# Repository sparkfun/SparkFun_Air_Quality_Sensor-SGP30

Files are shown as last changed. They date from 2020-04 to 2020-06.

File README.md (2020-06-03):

SparkFun Air Quality Sensor - SGP30 (Qwiic)
========================================

SparkFun Air Quality Sensor - SGP30

[*SparkFun Air Quality Sensor - SGP30 (Qwiic) (SEN-16531)*](https://www.sparkfun.com/products/16531)

The SGP30 is an Indoor Air Quality Sensor that outputs TVOC (in ppb) and CO<sub>2</sub> (in ppm) values along with raw measurements of H<sub>2</sub> and Ethanol.

Repository Contents
-------------------

* **/Hardware** - Eagle design files (.brd, .sch)
* **/Production** - Production panel files (.brd)

Documentation
--------------
* **[SGP30 Arduino Library](https://github.com/sparkfun/SparkFun_SGP30_Arduino_Library)** - Arduino library for the SparkFun Air Quality Sensor - SGP30.
* **[Hookup Guide](https://learn.sparkfun.com/tutorials/sparkfun-air-quality-sensor---sgp30-qwiic-hookup-guide)** - Basic hookup guide for the SparkFun Air Quality Sensor - SGP30. 
* **[SparkFun Fritzing repo](https://github.com/sparkfun/Fritzing_Parts)** - Fritzing diagrams for SparkFun products.
* **[SparkFun 3D Model repo](https://github.com/sparkfun/3D_Models)** - 3D models of SparkFun products.

Product Versions
----------------
* [SEN-16531](https://www.sparkfun.com/products/16531) - SparkFun initial release.
* [SPX-14813](https://www.sparkfun.com/products/14813) - Original SparkX Release.

License Information
-------------------

This product is _**open source**_! 

Please review the LICENSE.md file for license information. 

If you have any questions or concerns on licensing, please contact technical support on our [SparkFun forums](https://forum.sparkfun.com/viewforum.php?f=152).

Distributed as-is; no warranty is given.

- Your friends at SparkFun.

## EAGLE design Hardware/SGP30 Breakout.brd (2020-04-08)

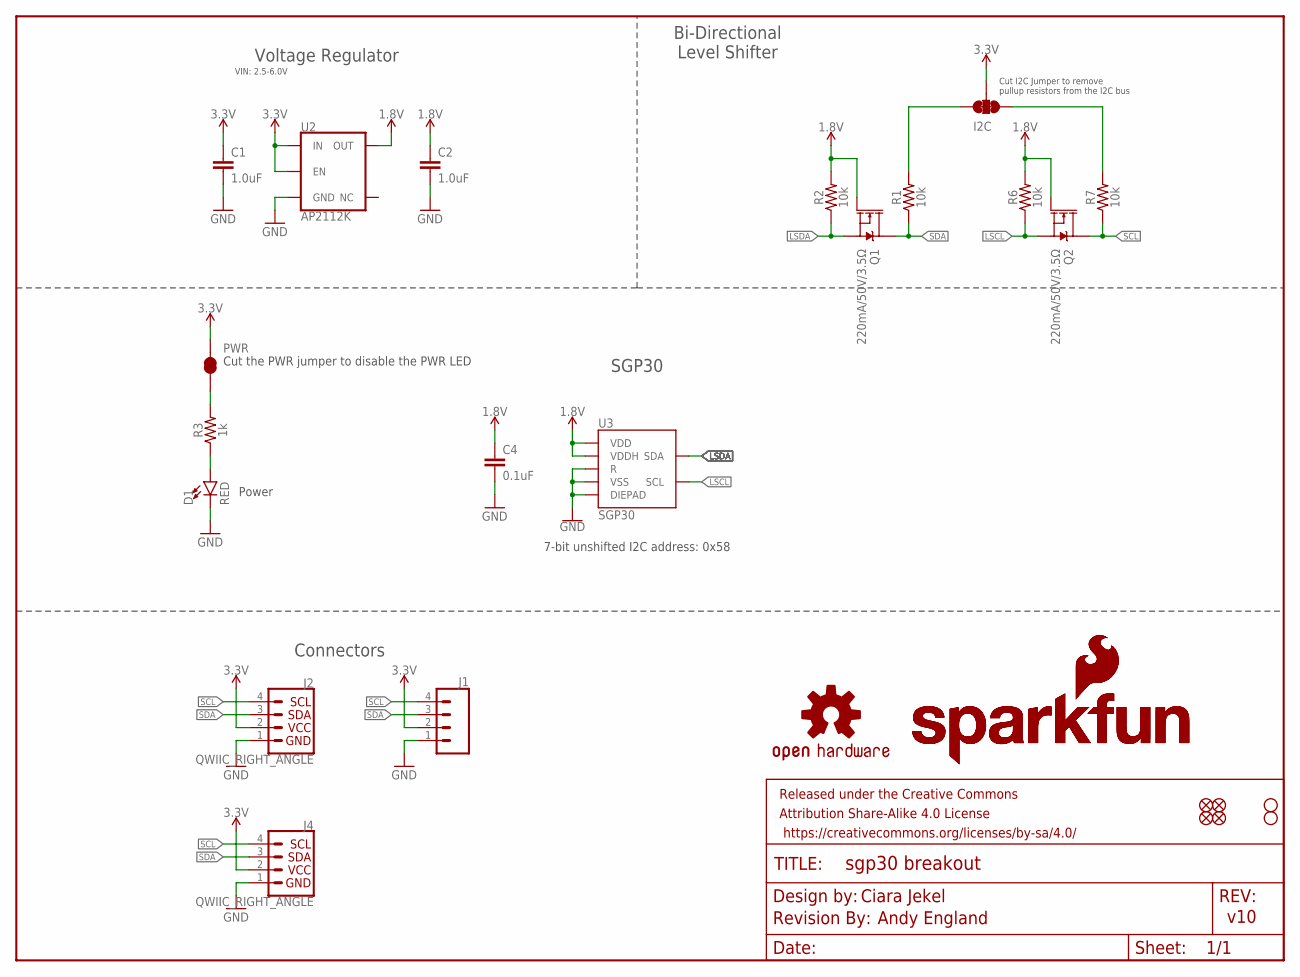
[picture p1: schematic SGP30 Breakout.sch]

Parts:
C1, C2: 1.0uF; 0603
C4: 0.1uF; 0603
D1: RED; LED-0603
FRAME1: FRAME-LETTER; CREATIVE_COMMONS
I2C: JUMPER-SMT_3_2-NC_TRACE_SILK; SMT-JUMPER_3_2-NC_TRACE_SILK
J1: CONN_041X04_NO_SILK; 1X04_NO_SILK
J2, J4: QWIIC_RIGHT_ANGLE; JST04_1MM_RA
JP1, JP2, JP5, JP6: FIDUCIALUFIDUCIAL; MICRO-FIDUCIAL
JP3, JP4: STAND-OFF
LOGO2: REVISION
LOGO3, LOGO4: SFE_LOGO_NAME_FLAME.1_INCH; SFE_LOGO_NAME_FLAME_.1
LOGO5: OSHW-LOGOS; OSHW-LOGO-S
PWR: JUMPER-SMT_2_NC_TRACE_SILK; SMT-JUMPER_2_NC_TRACE_SILK
Q1, Q2: 220mA/50V/3.5Ω; SOT23-3
R1, R2, R6, R7: 10k; 0603
R3: 1k; 0603
U2: AP2112K; SOT23-5
U3: SGP30

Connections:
1.8V: C2.1, C4.1, Q1.1 (G), Q2.1 (G), R2.2, R6.2, U2.5 (OUT), U3.1 (VDD), U3.5 (VDDH)
3.3V: C1.1, I2C.2, J1.2, J2.2, J4.2, PWR.2, U2.1 (IN), U2.3 (EN)
GND: C1.2, C2.2, C4.2, D1.C, J1.1, J2.1, J4.1, U2.2 (GND), U3.2 (VSS), U3.4 (R), U3.DIEPAD
LSCL: Q2.2 (S), R6.1, U3.6 (SCL)
LSDA: Q1.2 (S), R2.1, U3.3 (SDA)
unnamed: PWR.1, R3.2
unnamed: I2C.3, R1.2
unnamed: D1.A, R3.1
unnamed: I2C.1, R7.2
SCL: J1.4, J2.4, J4.4, Q2.3 (D), R7.1
SDA: J1.3, J2.3, J4.3, Q1.3 (D), R1.1

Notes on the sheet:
Ciara Jekel
v10
7-bit unshifted I2C address: 0x58
Power
Bi-Directional Level Shifter
Voltage Regulator
SGP30
Connectors
Cut the PWR jumper to disable the PWR LED
Andy England
VIN: 2.5-6.0V
Cut I2C Jumper to remove pullup resistors from the I2C bus

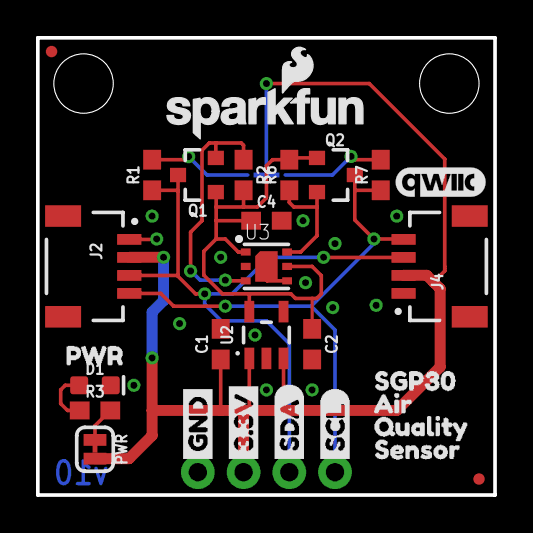
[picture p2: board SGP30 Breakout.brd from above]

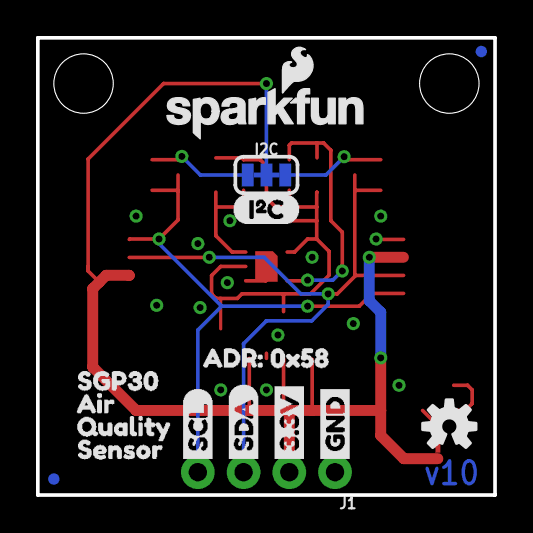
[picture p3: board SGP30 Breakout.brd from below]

Board: 2 copper layers, 25.4 x 25.4 mm, 49 parts (16 on the bottom side), 11 nets.

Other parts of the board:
U$1, U$11: _AIR1
U$2, U$12: QUALITY2
U$3, U$22: GND1
U$4, U$21: 3#3V2
U$5, U$27: SDA8
U$6, U$26: SCL9
U$7, U$13: SENSOR3
U$8, U$9: SGP300
U$14: ADR#_0X580
U$15: I2C
U$16: QWIIC_5MM
U$17: PWR_TO

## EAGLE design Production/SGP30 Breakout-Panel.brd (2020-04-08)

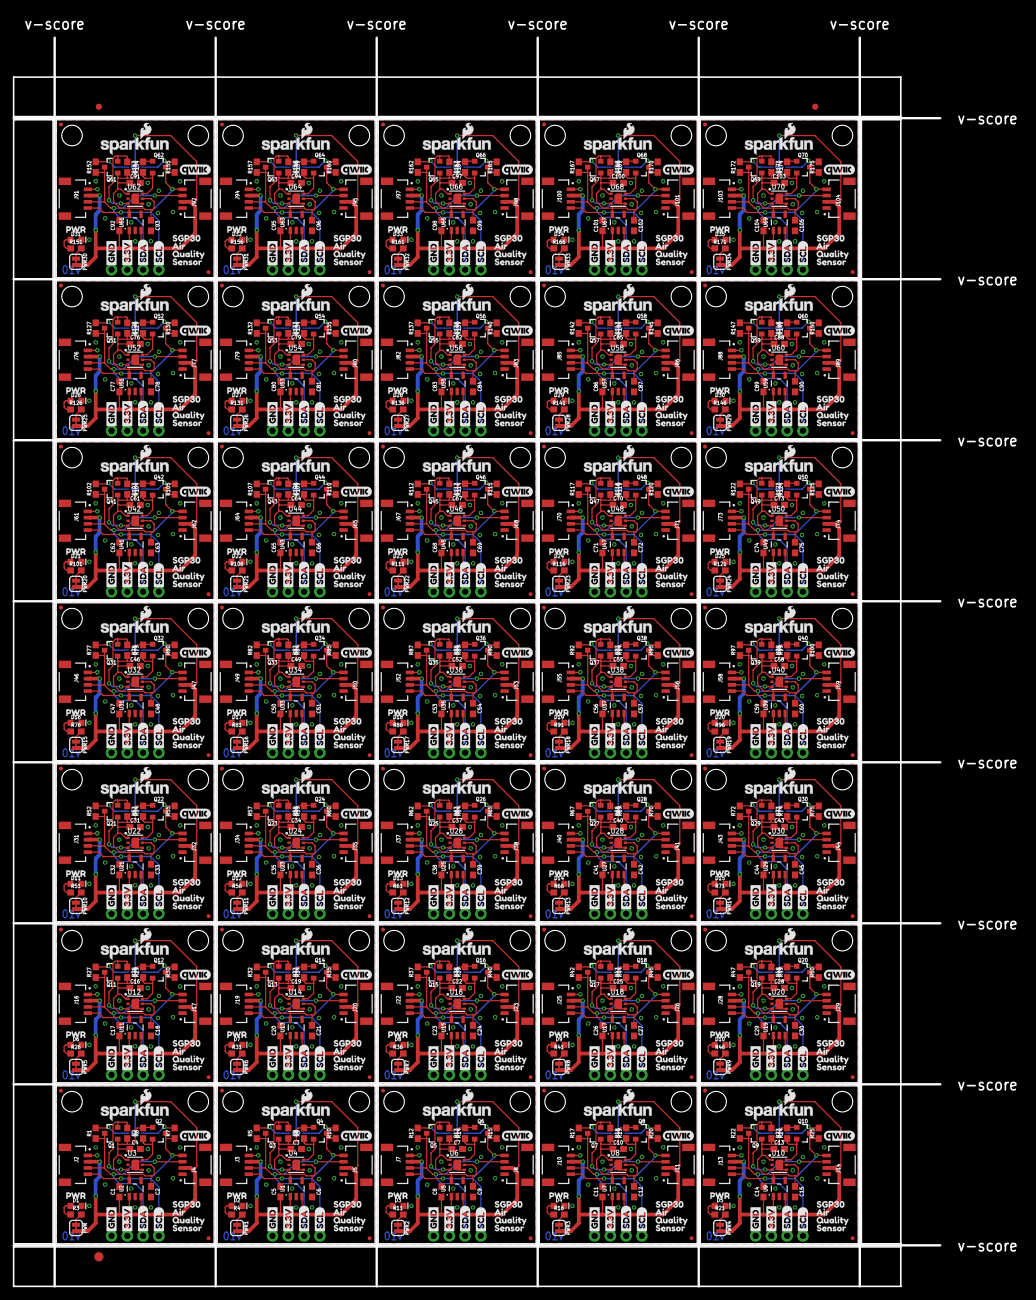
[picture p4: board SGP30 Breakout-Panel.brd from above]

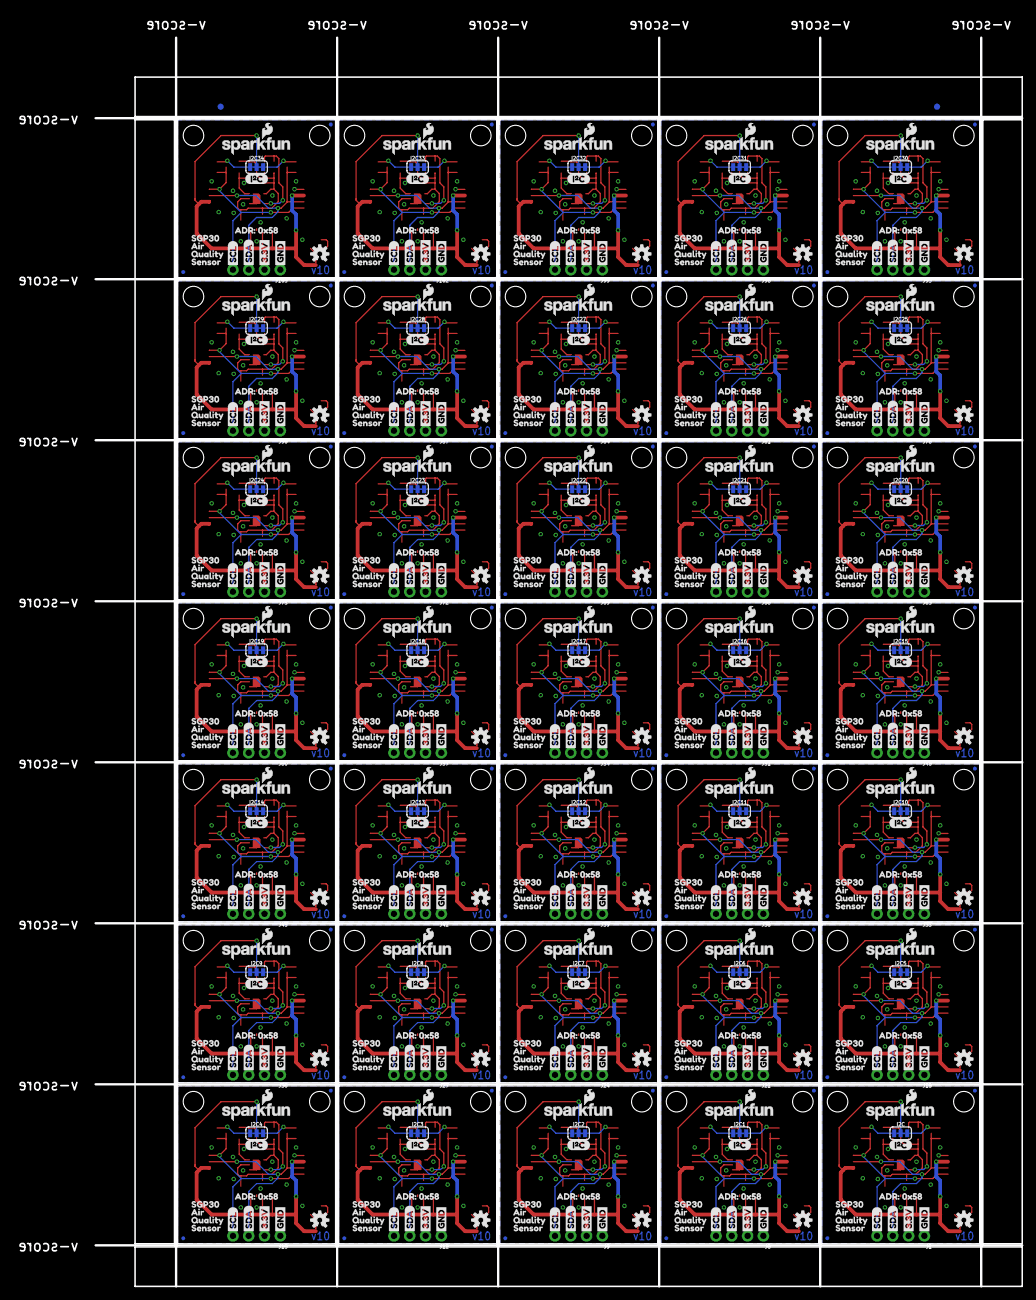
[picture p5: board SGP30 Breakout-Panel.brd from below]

Board: 2 copper layers, 149.1 x 200.9 mm, 1685 parts (562 on the bottom side), 385 nets.

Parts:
C1, C2, C5, C6, C8, C9, C11, C12, C14, C15, C17, C18, C20, C21, C23, C24, C26, C27, C29, C30, C32, C33, C35, C36, C38, C39, C41, C42, C44, C45, C47, C48, C50, C51, C53, C54, C56, C57, C59, C60, C62, C63, C65, C66, C68, C69, C71, C72, C74, C75, C77, C78, C80, C81, C83, C84, C86, C87, C89, C90, C92, C93, C95, C96, C98, C99, C101, C102, C104, C105: 1.0uF; 0603
C3, C4, C7, C10, C13, C16, C19, C22, C25, C28, C31, C34, C37, C40, C43, C46, C49, C52, C55, C58, C61, C64, C67, C70, C73, C76, C79, C82, C85, C88, C91, C94, C97, C100, C103: 0.1uF; 0603
D1, D2, D3, D4, D5, D6, D7, D8, D9, D10, D11, D12, D13, D14, D15, D16, D17, D18, D19, D20, D21, D22, D23, D24, D25, D26, D27, D28, D29, D30, D31, D32, D33, D34, D35: RED; LED-0603
E$1, E$2, E$3, E$4: FIDUCIAL-1X2
E$5: FIDUCIAL-1.5X3
I2C, I2C1, I2C2, I2C3, I2C4, I2C5, I2C6, I2C7, I2C8, I2C9, I2C10, I2C11, I2C12, I2C13, I2C14, I2C15, I2C16, I2C17, I2C18, I2C19, I2C20, I2C21, I2C22, I2C23, I2C24, I2C25, I2C26, I2C27, I2C28, I2C29, I2C30, I2C31, I2C32, I2C33, I2C34: JUMPER-SMT_3_2-NC_TRACE_SILK; SMT-JUMPER_3_2-NC_TRACE_SILK
J1, J6, J9, J12, J15, J18, J21, J24, J27, J30, J33, J36, J39, J42, J45, J48, J51, J54, J57, J60, J63, J66, J69, J72, J75, J78, J81, J84, J87, J90, J93, J96, J99, J102, J105: 1X04_NO_SILK
J2, J3, J4, J5, J7, J8, J10, J11, J13, J14, J16, J17, J19, J20, J22, J23, J25, J26, J28, J29, J31, J32, J34, J35, J37, J38, J40, J41, J43, J44, J46, J47, J49, J50, J52, J53, J55, J56, J58, J59, J61, J62, J64, J65, J67, J68, J70, J71, J73, J74, J76, J77, J79, J80, J82, J83, J85, J86, J88, J89, J91, J92, J94, J95, J97, J98, J100, J101, J103, J104: QWIIC_RIGHT_ANGLE; JST04_1MM_RA
JP1, JP2, JP5, JP6, JP9, JP10, JP11, JP12, JP15, JP16, JP17, JP18, JP21, JP22, JP23, JP24, JP27, JP28, JP29, JP30, JP33, JP34, JP35, JP36, JP39, JP40, JP41, JP42, JP45, JP46, JP47, JP48, JP51, JP52, JP53, JP54, JP57, JP58, JP59, JP60, JP63, JP64, JP65, JP66, JP69, JP70, JP71, JP72, JP75, JP76, JP77, JP78, JP81, JP82, JP83, JP84, JP87, JP88, JP89, JP90, JP93, JP94, JP95, JP96, JP99, JP100, JP101, JP102, JP105, JP106, JP107, JP108, JP111, JP112, JP113, JP114, JP117, JP118, JP119, JP120, JP123, JP124, JP125, JP126, JP129, JP130, JP131, JP132, JP135, JP136, JP137, JP138, JP141, JP142, JP143, JP144, JP147, JP148, JP149, JP150, JP153, JP154, JP155, JP156, JP159, JP160, JP161, JP162, JP165, JP166, JP167, JP168, JP171, JP172, JP173, JP174, JP177, JP178, JP179, JP180, JP183, JP184, JP185, JP186, JP189, JP190, JP191, JP192, JP195, JP196, JP197, JP198, JP201, JP202, JP203, JP204, JP207, JP208, JP209, JP210: FIDUCIALUFIDUCIAL; MICRO-FIDUCIAL
JP3, JP4, JP7, JP8, JP13, JP14, JP19, JP20, JP25, JP26, JP31, JP32, JP37, JP38, JP43, JP44, JP49, JP50, JP55, JP56, JP61, JP62, JP67, JP68, JP73, JP74, JP79, JP80, JP85, JP86, JP91, JP92, JP97, JP98, JP103, JP104, JP109, JP110, JP115, JP116, JP121, JP122, JP127, JP128, JP133, JP134, JP139, JP140, JP145, JP146, JP151, JP152, JP157, JP158, JP163, JP164, JP169, JP170, JP175, JP176, JP181, JP182, JP187, JP188, JP193, JP194, JP199, JP200, JP205, JP206: STAND-OFF
LOGO1, LOGO2, LOGO9, LOGO13, LOGO17, LOGO21, LOGO25, LOGO29, LOGO33, LOGO37, LOGO41, LOGO45, LOGO49, LOGO53, LOGO57, LOGO61, LOGO65, LOGO69, LOGO73, LOGO77, LOGO81, LOGO85, LOGO89, LOGO93, LOGO97, LOGO101, LOGO105, LOGO109, LOGO113, LOGO117, LOGO121, LOGO125, LOGO129, LOGO133, LOGO137: REVISION
LOGO3, LOGO4, LOGO6, LOGO7, LOGO10, LOGO11, LOGO14, LOGO15, LOGO18, LOGO19, LOGO22, LOGO23, LOGO26, LOGO27, LOGO30, LOGO31, LOGO34, LOGO35, LOGO38, LOGO39, LOGO42, LOGO43, LOGO46, LOGO47, LOGO50, LOGO51, LOGO54, LOGO55, LOGO58, LOGO59, LOGO62, LOGO63, LOGO66, LOGO67, LOGO70, LOGO71, LOGO74, LOGO75, LOGO78, LOGO79, LOGO82, LOGO83, LOGO86, LOGO87, LOGO90, LOGO91, LOGO94, LOGO95, LOGO98, LOGO99, LOGO102, LOGO103, LOGO106, LOGO107, LOGO110, LOGO111, LOGO114, LOGO115, LOGO118, LOGO119, LOGO122, LOGO123, LOGO126, LOGO127, LOGO130, LOGO131, LOGO134, LOGO135, LOGO138, LOGO139: SFE_LOGO_NAME_FLAME.1_INCH; SFE_LOGO_NAME_FLAME_.1
LOGO5, LOGO8, LOGO12, LOGO16, LOGO20, LOGO24, LOGO28, LOGO32, LOGO36, LOGO40, LOGO44, LOGO48, LOGO52, LOGO56, LOGO60, LOGO64, LOGO68, LOGO72, LOGO76, LOGO80, LOGO84, LOGO88, LOGO92, LOGO96, LOGO100, LOGO104, LOGO108, LOGO112, LOGO116, LOGO120, LOGO124, LOGO128, LOGO132, LOGO136, LOGO140: OSHW-LOGOS; OSHW-LOGO-S
PWR, PWR1, PWR2, PWR3, PWR4, PWR5, PWR6, PWR7, PWR8, PWR9, PWR10, PWR11, PWR12, PWR13, PWR14, PWR15, PWR16, PWR17, PWR18, PWR19, PWR20, PWR21, PWR22, PWR23, PWR24, PWR25, PWR26, PWR27, PWR28, PWR29, PWR30, PWR31, PWR32, PWR33, PWR34: JUMPER-SMT_2_NC_TRACE_SILK; SMT-JUMPER_2_NC_TRACE_SILK
Q1, Q2, Q3, Q4, Q5, Q6, Q7, Q8, Q9, Q10, Q11, Q12, Q13, Q14, Q15, Q16, Q17, Q18, Q19, Q20, Q21, Q22, Q23, Q24, Q25, Q26, Q27, Q28, Q29, Q30, Q31, Q32, Q33, Q34, Q35, Q36, Q37, Q38, Q39, Q40, Q41, Q42, Q43, Q44, Q45, Q46, Q47, Q48, Q49, Q50, Q51, Q52, Q53, Q54, Q55, Q56, Q57, Q58, Q59, Q60, Q61, Q62, Q63, Q64, Q65, Q66, Q67, Q68, Q69, Q70: 220mA/50V/3.5Ω; SOT23-3
R1, R2, R5, R6, R7, R8, R9, R10, R12, R13, R14, R15, R17, R18, R19, R20, R22, R23, R24, R25, R27, R28, R29, R30, R32, R33, R34, R35, R37, R38, R39, R40, R42, R43, R44, R45, R47, R48, R49, R50, R52, R53, R54, R55, R57, R58, R59, R60, R62, R63, R64, R65, R67, R68, R69, R70, R72, R73, R74, R75, R77, R78, R79, R80, R82, R83, R84, R85, R87, R88, R89, R90, R92, R93, R94, R95, R97, R98, R99, R100, R102, R103, R104, R105, R107, R108, R109, R110, R112, R113, R114, R115, R117, R118, R119, R120, R122, R123, R124, R125, R127, R128, R129, R130, R132, R133, R134, R135, R137, R138, R139, R140, R142, R143, R144, R145, R147, R148, R149, R150, R152, R153, R154, R155, R157, R158, R159, R160, R162, R163, R164, R165, R167, R168, R169, R170, R172, R173, R174, R175: 10k; 0603
R3, R4, R11, R16, R21, R26, R31, R36, R41, R46, R51, R56, R61, R66, R71, R76, R81, R86, R91, R96, R101, R106, R111, R116, R121, R126, R131, R136, R141, R146, R151, R156, R161, R166, R171: 1k; 0603
U1, U2, U5, U7, U9, U11, U13, U15, U17, U19, U21, U23, U25, U27, U29, U31, U33, U35, U37, U39, U41, U43, U45, U47, U49, U51, U53, U55, U57, U59, U61, U63, U65, U67, U69: AP2112K; SOT23-5
U3, U4, U6, U8, U10, U12, U14, U16, U18, U20, U22, U24, U26, U28, U30, U32, U34, U36, U38, U40, U42, U44, U46, U48, U50, U52, U54, U56, U58, U60, U62, U64, U66, U68, U70: SGP30
U$1, U$11, U$29, U$34, U$49, U$54, U$69, U$74, U$89, U$94, U$109, U$114, U$129, U$134, U$149, U$154, U$169, U$174, U$189, U$194, U$209, U$214, U$229, U$234, U$249, U$254, U$269, U$274, U$289, U$294, U$309, U$314, U$329, U$334, U$349, U$354, U$369, U$374, U$389, U$394, U$409, U$414, U$429, U$434, U$449, U$454, U$469, U$474, U$489, U$494, U$509, U$514, U$529, U$534, U$549, U$554, U$569, U$574, U$589, U$594, U$609, U$614, U$629, U$634, U$649, U$654, U$669, U$674, U$689, U$694: _AIR1
U$2, U$12, U$30, U$35, U$50, U$55, U$70, U$75, U$90, U$95, U$110, U$115, U$130, U$135, U$150, U$155, U$170, U$175, U$190, U$195, U$210, U$215, U$230, U$235, U$250, U$255, U$270, U$275, U$290, U$295, U$310, U$315, U$330, U$335, U$350, U$355, U$370, U$375, U$390, U$395, U$410, U$415, U$430, U$435, U$450, U$455, U$470, U$475, U$490, U$495, U$510, U$515, U$530, U$535, U$550, U$555, U$570, U$575, U$590, U$595, U$610, U$615, U$630, U$635, U$650, U$655, U$670, U$675, U$690, U$695: QUALITY2
U$3, U$18, U$22, U$23, U$42, U$45, U$62, U$65, U$82, U$85, U$102, U$105, U$122, U$125, U$142, U$145, U$162, U$165, U$182, U$185, U$202, U$205, U$222, U$225, U$242, U$245, U$262, U$265, U$282, U$285, U$302, U$305, U$322, U$325, U$342, U$345, U$362, U$365, U$382, U$385, U$402, U$405, U$422, U$425, U$442, U$445, U$462, U$465, U$482, U$485, U$502, U$505, U$522, U$525, U$542, U$545, U$562, U$565, U$582, U$585, U$602, U$605, U$622, U$625, U$642, U$645, U$662, U$665, U$682, U$685: GND1
U$4, U$10, U$21, U$24, U$41, U$46, U$61, U$66, U$81, U$86, U$101, U$106, U$121, U$126, U$141, U$146, U$161, U$166, U$181, U$186, U$201, U$206, U$221, U$226, U$241, U$246, U$261, U$266, U$281, U$286, U$301, U$306, U$321, U$326, U$341, U$346, U$361, U$366, U$381, U$386, U$401, U$406, U$421, U$426, U$441, U$446, U$461, U$466, U$481, U$486, U$501, U$506, U$521, U$526, U$541, U$546, U$561, U$566, U$581, U$586, U$601, U$606, U$621, U$626, U$641, U$646, U$661, U$666, U$681, U$686: 3#3V2
U$5, U$20, U$25, U$27, U$44, U$47, U$64, U$67, U$84, U$87, U$104, U$107, U$124, U$127, U$144, U$147, U$164, U$167, U$184, U$187, U$204, U$207, U$224, U$227, U$244, U$247, U$264, U$267, U$284, U$287, U$304, U$307, U$324, U$327, U$344, U$347, U$364, U$367, U$384, U$387, U$404, U$407, U$424, U$427, U$444, U$447, U$464, U$467, U$484, U$487, U$504, U$507, U$524, U$527, U$544, U$547, U$564, U$567, U$584, U$587, U$604, U$607, U$624, U$627, U$644, U$647, U$664, U$667, U$684, U$687: SDA8
U$6, U$19, U$26, U$28, U$43, U$48, U$63, U$68, U$83, U$88, U$103, U$108, U$123, U$128, U$143, U$148, U$163, U$168, U$183, U$188, U$203, U$208, U$223, U$228, U$243, U$248, U$263, U$268, U$283, U$288, U$303, U$308, U$323, U$328, U$343, U$348, U$363, U$368, U$383, U$388, U$403, U$408, U$423, U$428, U$443, U$448, U$463, U$468, U$483, U$488, U$503, U$508, U$523, U$528, U$543, U$548, U$563, U$568, U$583, U$588, U$603, U$608, U$623, U$628, U$643, U$648, U$663, U$668, U$683, U$688: SCL9
U$7, U$13, U$31, U$36, U$51, U$56, U$71, U$76, U$91, U$96, U$111, U$116, U$131, U$136, U$151, U$156, U$171, U$176, U$191, U$196, U$211, U$216, U$231, U$236, U$251, U$256, U$271, U$276, U$291, U$296, U$311, U$316, U$331, U$336, U$351, U$356, U$371, U$376, U$391, U$396, U$411, U$416, U$431, U$436, U$451, U$456, U$471, U$476, U$491, U$496, U$511, U$516, U$531, U$536, U$551, U$556, U$571, U$576, U$591, U$596, U$611, U$616, U$631, U$636, U$651, U$656, U$671, U$676, U$691, U$696: SENSOR3
U$8, U$9, U$32, U$33, U$52, U$53, U$72, U$73, U$92, U$93, U$112, U$113, U$132, U$133, U$152, U$153, U$172, U$173, U$192, U$193, U$212, U$213, U$232, U$233, U$252, U$253, U$272, U$273, U$292, U$293, U$312, U$313, U$332, U$333, U$352, U$353, U$372, U$373, U$392, U$393, U$412, U$413, U$432, U$433, U$452, U$453, U$472, U$473, U$492, U$493, U$512, U$513, U$532, U$533, U$552, U$553, U$572, U$573, U$592, U$593, U$612, U$613, U$632, U$633, U$652, U$653, U$672, U$673, U$692, U$693: SGP300
U$14, U$37, U$57, U$77, U$97, U$117, U$137, U$157, U$177, U$197, U$217, U$237, U$257, U$277, U$297, U$317, U$337, U$357, U$377, U$397, U$417, U$437, U$457, U$477, U$497, U$517, U$537, U$557, U$577, U$597, U$617, U$637, U$657, U$677, U$697: ADR#_0X580
U$15, U$38, U$58, U$78, U$98, U$118, U$138, U$158, U$178, U$198, U$218, U$238, U$258, U$278, U$298, U$318, U$338, U$358, U$378, U$398, U$418, U$438, U$458, U$478, U$498, U$518, U$538, U$558, U$578, U$598, U$618, U$638, U$658, U$678, U$698: I2C
U$16, U$39, U$59, U$79, U$99, U$119, U$139, U$159, U$179, U$199, U$219, U$239, U$259, U$279, U$299, U$319, U$339, U$359, U$379, U$399, U$419, U$439, U$459, U$479, U$499, U$519, U$539, U$559, U$579, U$599, U$619, U$639, U$659, U$679, U$699: QWIIC_5MM
U$17, U$40, U$60, U$80, U$100, U$120, U$140, U$160, U$180, U$200, U$220, U$240, U$260, U$280, U$300, U$320, U$340, U$360, U$380, U$400, U$420, U$440, U$460, U$480, U$500, U$520, U$540, U$560, U$580, U$600, U$620, U$640, U$660, U$680, U$700: PWR_TO

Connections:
1.8V: C2.1, C4.1, Q1.1, Q2.1, R2.2, R6.2, U2.5, U3.1, U3.5
1.8V1: C3.1, C6.1, Q3.1, Q4.1, R8.2, R9.2, U1.5, U4.1, U4.5
1.8V2: C7.1, C9.1, Q5.1, Q6.1, R13.2, R14.2, U5.5, U6.1, U6.5
1.8V3: C10.1, C12.1, Q7.1, Q8.1, R18.2, R19.2, U7.5, U8.1, U8.5
1.8V4: C13.1, C15.1, Q9.1, Q10.1, R23.2, R24.2, U9.5, U10.1, U10.5
1.8V5: C16.1, C18.1, Q11.1, Q12.1, R28.2, R29.2, U11.5, U12.1, U12.5
1.8V6: C19.1, C21.1, Q13.1, Q14.1, R33.2, R34.2, U13.5, U14.1, U14.5
1.8V7: C22.1, C24.1, Q15.1, Q16.1, R38.2, R39.2, U15.5, U16.1, U16.5
1.8V8: C25.1, C27.1, Q17.1, Q18.1, R43.2, R44.2, U17.5, U18.1, U18.5
1.8V9: C28.1, C30.1, Q19.1, Q20.1, R48.2, R49.2, U19.5, U20.1, U20.5
1.8V10: C31.1, C33.1, Q21.1, Q22.1, R53.2, R54.2, U21.5, U22.1, U22.5
1.8V11: C34.1, C36.1, Q23.1, Q24.1, R58.2, R59.2, U23.5, U24.1, U24.5
1.8V12: C37.1, C39.1, Q25.1, Q26.1, R63.2, R64.2, U25.5, U26.1, U26.5
1.8V13: C40.1, C42.1, Q27.1, Q28.1, R68.2, R69.2, U27.5, U28.1, U28.5
1.8V14: C43.1, C45.1, Q29.1, Q30.1, R73.2, R74.2, U29.5, U30.1, U30.5
1.8V15: C46.1, C48.1, Q31.1, Q32.1, R78.2, R79.2, U31.5, U32.1, U32.5
1.8V16: C49.1, C51.1, Q33.1, Q34.1, R83.2, R84.2, U33.5, U34.1, U34.5
1.8V17: C52.1, C54.1, Q35.1, Q36.1, R88.2, R89.2, U35.5, U36.1, U36.5
1.8V18: C55.1, C57.1, Q37.1, Q38.1, R93.2, R94.2, U37.5, U38.1, U38.5
1.8V19: C58.1, C60.1, Q39.1, Q40.1, R98.2, R99.2, U39.5, U40.1, U40.5
1.8V20: C61.1, C63.1, Q41.1, Q42.1, R103.2, R104.2, U41.5, U42.1, U42.5
1.8V21: C64.1, C66.1, Q43.1, Q44.1, R108.2, R109.2, U43.5, U44.1, U44.5
1.8V22: C67.1, C69.1, Q45.1, Q46.1, R113.2, R114.2, U45.5, U46.1, U46.5
1.8V23: C70.1, C72.1, Q47.1, Q48.1, R118.2, R119.2, U47.5, U48.1, U48.5
1.8V24: C73.1, C75.1, Q49.1, Q50.1, R123.2, R124.2, U49.5, U50.1, U50.5
1.8V25: C76.1, C78.1, Q51.1, Q52.1, R128.2, R129.2, U51.5, U52.1, U52.5
1.8V26: C79.1, C81.1, Q53.1, Q54.1, R133.2, R134.2, U53.5, U54.1, U54.5
1.8V27: C82.1, C84.1, Q55.1, Q56.1, R138.2, R139.2, U55.5, U56.1, U56.5
1.8V28: C85.1, C87.1, Q57.1, Q58.1, R143.2, R144.2, U57.5, U58.1, U58.5
1.8V29: C88.1, C90.1, Q59.1, Q60.1, R148.2, R149.2, U59.5, U60.1, U60.5
1.8V30: C91.1, C93.1, Q61.1, Q62.1, R153.2, R154.2, U61.5, U62.1, U62.5
1.8V31: C94.1, C96.1, Q63.1, Q64.1, R158.2, R159.2, U63.5, U64.1, U64.5
1.8V32: C97.1, C99.1, Q65.1, Q66.1, R163.2, R164.2, U65.5, U66.1, U66.5
1.8V33: C100.1, C102.1, Q67.1, Q68.1, R168.2, R169.2, U67.5, U68.1, U68.5
1.8V34: C103.1, C105.1, Q69.1, Q70.1, R173.2, R174.2, U69.5, U70.1, U70.5
3.3V: C1.1, I2C.2, J1.2, J2.2, J4.2, PWR.2, U2.1, U2.3
3.3V1: C5.1, I2C1.2, J3.2, J5.2, J6.2, PWR1.2, U1.1, U1.3
3.3V2: C8.1, I2C2.2, J7.2, J8.2, J9.2, PWR2.2, U5.1, U5.3
3.3V3: C11.1, I2C3.2, J10.2, J11.2, J12.2, PWR3.2, U7.1, U7.3
3.3V4: C14.1, I2C4.2, J13.2, J14.2, J15.2, PWR4.2, U9.1, U9.3
3.3V5: C17.1, I2C5.2, J16.2, J17.2, J18.2, PWR5.2, U11.1, U11.3
3.3V6: C20.1, I2C6.2, J19.2, J20.2, J21.2, PWR6.2, U13.1, U13.3
3.3V7: C23.1, I2C7.2, J22.2, J23.2, J24.2, PWR7.2, U15.1, U15.3
3.3V8: C26.1, I2C8.2, J25.2, J26.2, J27.2, PWR8.2, U17.1, U17.3
3.3V9: C29.1, I2C9.2, J28.2, J29.2, J30.2, PWR9.2, U19.1, U19.3
3.3V10: C32.1, I2C10.2, J31.2, J32.2, J33.2, PWR10.2, U21.1, U21.3
3.3V11: C35.1, I2C11.2, J34.2, J35.2, J36.2, PWR11.2, U23.1, U23.3
3.3V12: C38.1, I2C12.2, J37.2, J38.2, J39.2, PWR12.2, U25.1, U25.3
3.3V13: C41.1, I2C13.2, J40.2, J41.2, J42.2, PWR13.2, U27.1, U27.3
3.3V14: C44.1, I2C14.2, J43.2, J44.2, J45.2, PWR14.2, U29.1, U29.3
3.3V15: C47.1, I2C15.2, J46.2, J47.2, J48.2, PWR15.2, U31.1, U31.3
3.3V16: C50.1, I2C16.2, J49.2, J50.2, J51.2, PWR16.2, U33.1, U33.3
3.3V17: C53.1, I2C17.2, J52.2, J53.2, J54.2, PWR17.2, U35.1, U35.3
3.3V18: C56.1, I2C18.2, J55.2, J56.2, J57.2, PWR18.2, U37.1, U37.3
3.3V19: C59.1, I2C19.2, J58.2, J59.2, J60.2, PWR19.2, U39.1, U39.3
3.3V20: C62.1, I2C20.2, J61.2, J62.2, J63.2, PWR20.2, U41.1, U41.3
3.3V21: C65.1, I2C21.2, J64.2, J65.2, J66.2, PWR21.2, U43.1, U43.3
3.3V22: C68.1, I2C22.2, J67.2, J68.2, J69.2, PWR22.2, U45.1, U45.3
3.3V23: C71.1, I2C23.2, J70.2, J71.2, J72.2, PWR23.2, U47.1, U47.3
3.3V24: C74.1, I2C24.2, J73.2, J74.2, J75.2, PWR24.2, U49.1, U49.3
3.3V25: C77.1, I2C25.2, J76.2, J77.2, J78.2, PWR25.2, U51.1, U51.3
3.3V26: C80.1, I2C26.2, J79.2, J80.2, J81.2, PWR26.2, U53.1, U53.3
3.3V27: C83.1, I2C27.2, J82.2, J83.2, J84.2, PWR27.2, U55.1, U55.3
3.3V28: C86.1, I2C28.2, J85.2, J86.2, J87.2, PWR28.2, U57.1, U57.3
3.3V29: C89.1, I2C29.2, J88.2, J89.2, J90.2, PWR29.2, U59.1, U59.3
3.3V30: C92.1, I2C30.2, J91.2, J92.2, J93.2, PWR30.2, U61.1, U61.3
3.3V31: C95.1, I2C31.2, J94.2, J95.2, J96.2, PWR31.2, U63.1, U63.3
3.3V32: C98.1, I2C32.2, J97.2, J98.2, J99.2, PWR32.2, U65.1, U65.3
3.3V33: C101.1, I2C33.2, J100.2, J101.2, J102.2, PWR33.2, U67.1, U67.3
3.3V34: C104.1, I2C34.2, J103.2, J104.2, J105.2, PWR34.2, U69.1, U69.3
GND: C1.2, C2.2, C4.2, D1.C, J1.1, J2.1, J4.1, U2.2, U3.2, U3.4, U3.DIEPAD
GND1: C3.2, C5.2, C6.2, D2.C, J3.1, J5.1, J6.1, U1.2, U4.2, U4.4, U4.DIEPAD
GND2: C7.2, C8.2, C9.2, D3.C, J7.1, J8.1, J9.1, U5.2, U6.2, U6.4, U6.DIEPAD
GND3: C10.2, C11.2, C12.2, D4.C, J10.1, J11.1, J12.1, U7.2, U8.2, U8.4, U8.DIEPAD
GND4: C13.2, C14.2, C15.2, D5.C, J13.1, J14.1, J15.1, U9.2, U10.2, U10.4, U10.DIEPAD
GND5: C16.2, C17.2, C18.2, D6.C, J16.1, J17.1, J18.1, U11.2, U12.2, U12.4, U12.DIEPAD
GND6: C19.2, C20.2, C21.2, D7.C, J19.1, J20.1, J21.1, U13.2, U14.2, U14.4, U14.DIEPAD
GND7: C22.2, C23.2, C24.2, D8.C, J22.1, J23.1, J24.1, U15.2, U16.2, U16.4, U16.DIEPAD
GND8: C25.2, C26.2, C27.2, D9.C, J25.1, J26.1, J27.1, U17.2, U18.2, U18.4, U18.DIEPAD
GND9: C28.2, C29.2, C30.2, D10.C, J28.1, J29.1, J30.1, U19.2, U20.2, U20.4, U20.DIEPAD
GND10: C31.2, C32.2, C33.2, D11.C, J31.1, J32.1, J33.1, U21.2, U22.2, U22.4, U22.DIEPAD
GND11: C34.2, C35.2, C36.2, D12.C, J34.1, J35.1, J36.1, U23.2, U24.2, U24.4, U24.DIEPAD
GND12: C37.2, C38.2, C39.2, D13.C, J37.1, J38.1, J39.1, U25.2, U26.2, U26.4, U26.DIEPAD
GND13: C40.2, C41.2, C42.2, D14.C, J40.1, J41.1, J42.1, U27.2, U28.2, U28.4, U28.DIEPAD
GND14: C43.2, C44.2, C45.2, D15.C, J43.1, J44.1, J45.1, U29.2, U30.2, U30.4, U30.DIEPAD
GND15: C46.2, C47.2, C48.2, D16.C, J46.1, J47.1, J48.1, U31.2, U32.2, U32.4, U32.DIEPAD
GND16: C49.2, C50.2, C51.2, D17.C, J49.1, J50.1, J51.1, U33.2, U34.2, U34.4, U34.DIEPAD
GND17: C52.2, C53.2, C54.2, D18.C, J52.1, J53.1, J54.1, U35.2, U36.2, U36.4, U36.DIEPAD
GND18: C55.2, C56.2, C57.2, D19.C, J55.1, J56.1, J57.1, U37.2, U38.2, U38.4, U38.DIEPAD
GND19: C58.2, C59.2, C60.2, D20.C, J58.1, J59.1, J60.1, U39.2, U40.2, U40.4, U40.DIEPAD
GND20: C61.2, C62.2, C63.2, D21.C, J61.1, J62.1, J63.1, U41.2, U42.2, U42.4, U42.DIEPAD
GND21: C64.2, C65.2, C66.2, D22.C, J64.1, J65.1, J66.1, U43.2, U44.2, U44.4, U44.DIEPAD
GND22: C67.2, C68.2, C69.2, D23.C, J67.1, J68.1, J69.1, U45.2, U46.2, U46.4, U46.DIEPAD
GND23: C70.2, C71.2, C72.2, D24.C, J70.1, J71.1, J72.1, U47.2, U48.2, U48.4, U48.DIEPAD
GND24: C73.2, C74.2, C75.2, D25.C, J73.1, J74.1, J75.1, U49.2, U50.2, U50.4, U50.DIEPAD
GND25: C76.2, C77.2, C78.2, D26.C, J76.1, J77.1, J78.1, U51.2, U52.2, U52.4, U52.DIEPAD
GND26: C79.2, C80.2, C81.2, D27.C, J79.1, J80.1, J81.1, U53.2, U54.2, U54.4, U54.DIEPAD
GND27: C82.2, C83.2, C84.2, D28.C, J82.1, J83.1, J84.1, U55.2, U56.2, U56.4, U56.DIEPAD
GND28: C85.2, C86.2, C87.2, D29.C, J85.1, J86.1, J87.1, U57.2, U58.2, U58.4, U58.DIEPAD
GND29: C88.2, C89.2, C90.2, D30.C, J88.1, J89.1, J90.1, U59.2, U60.2, U60.4, U60.DIEPAD
GND30: C91.2, C92.2, C93.2, D31.C, J91.1, J92.1, J93.1, U61.2, U62.2, U62.4, U62.DIEPAD
GND31: C94.2, C95.2, C96.2, D32.C, J94.1, J95.1, J96.1, U63.2, U64.2, U64.4, U64.DIEPAD
GND32: C97.2, C98.2, C99.2, D33.C, J97.1, J98.1, J99.1, U65.2, U66.2, U66.4, U66.DIEPAD
GND33: C100.2, C101.2, C102.2, D34.C, J100.1, J101.1, J102.1, U67.2, U68.2, U68.4, U68.DIEPAD
GND34: C103.2, C104.2, C105.2, D35.C, J103.1, J104.1, J105.1, U69.2, U70.2, U70.4, U70.DIEPAD
LSCL: Q2.2, R6.1, U3.6
LSCL1: Q4.2, R9.1, U4.6
LSCL2: Q6.2, R14.1, U6.6
LSCL3: Q8.2, R19.1, U8.6
LSCL4: Q10.2, R24.1, U10.6
LSCL5: Q12.2, R29.1, U12.6
LSCL6: Q14.2, R34.1, U14.6
LSCL7: Q16.2, R39.1, U16.6
LSCL8: Q18.2, R44.1, U18.6
LSCL9: Q20.2, R49.1, U20.6
LSCL10: Q22.2, R54.1, U22.6
LSCL11: Q24.2, R59.1, U24.6
LSCL12: Q26.2, R64.1, U26.6
LSCL13: Q28.2, R69.1, U28.6
LSCL14: Q30.2, R74.1, U30.6
LSCL15: Q32.2, R79.1, U32.6
LSCL16: Q34.2, R84.1, U34.6
LSCL17: Q36.2, R89.1, U36.6
LSCL18: Q38.2, R94.1, U38.6
LSCL19: Q40.2, R99.1, U40.6
LSCL20: Q42.2, R104.1, U42.6
LSCL21: Q44.2, R109.1, U44.6
LSCL22: Q46.2, R114.1, U46.6
LSCL23: Q48.2, R119.1, U48.6
LSCL24: Q50.2, R124.1, U50.6
LSCL25: Q52.2, R129.1, U52.6
LSCL26: Q54.2, R134.1, U54.6
LSCL27: Q56.2, R139.1, U56.6
LSCL28: Q58.2, R144.1, U58.6
LSCL29: Q60.2, R149.1, U60.6
LSCL30: Q62.2, R154.1, U62.6
LSCL31: Q64.2, R159.1, U64.6
LSCL32: Q66.2, R164.1, U66.6
LSCL33: Q68.2, R169.1, U68.6
LSCL34: Q70.2, R174.1, U70.6
LSDA: Q1.2, R2.1, U3.3
LSDA1: Q3.2, R8.1, U4.3
LSDA2: Q5.2, R13.1, U6.3
LSDA3: Q7.2, R18.1, U8.3
LSDA4: Q9.2, R23.1, U10.3
LSDA5: Q11.2, R28.1, U12.3
LSDA6: Q13.2, R33.1, U14.3
LSDA7: Q15.2, R38.1, U16.3
LSDA8: Q17.2, R43.1, U18.3
LSDA9: Q19.2, R48.1, U20.3
LSDA10: Q21.2, R53.1, U22.3
LSDA11: Q23.2, R58.1, U24.3
LSDA12: Q25.2, R63.1, U26.3
LSDA13: Q27.2, R68.1, U28.3
LSDA14: Q29.2, R73.1, U30.3
LSDA15: Q31.2, R78.1, U32.3
LSDA16: Q33.2, R83.1, U34.3
LSDA17: Q35.2, R88.1, U36.3
LSDA18: Q37.2, R93.1, U38.3
LSDA19: Q39.2, R98.1, U40.3
LSDA20: Q41.2, R103.1, U42.3
LSDA21: Q43.2, R108.1, U44.3
LSDA22: Q45.2, R113.1, U46.3
LSDA23: Q47.2, R118.1, U48.3
LSDA24: Q49.2, R123.1, U50.3
LSDA25: Q51.2, R128.1, U52.3
LSDA26: Q53.2, R133.1, U54.3
LSDA27: Q55.2, R138.1, U56.3
LSDA28: Q57.2, R143.1, U58.3
LSDA29: Q59.2, R148.1, U60.3
LSDA30: Q61.2, R153.1, U62.3
LSDA31: Q63.2, R158.1, U64.3
LSDA32: Q65.2, R163.1, U66.3
LSDA33: Q67.2, R168.1, U68.3
LSDA34: Q69.2, R173.1, U70.3
unnamed: PWR.1, R3.2
unnamed: I2C.3, R1.2
unnamed: D1.A, R3.1
unnamed: I2C.1, R7.2
unnamed: D2.A, R4.1
unnamed: PWR1.1, R4.2
unnamed: I2C1.3, R5.2
unnamed: I2C1.1, R10.2
unnamed: D3.A, R11.1
unnamed: PWR2.1, R11.2
unnamed: I2C2.3, R12.2
unnamed: I2C2.1, R15.2
unnamed: D4.A, R16.1
unnamed: PWR3.1, R16.2
unnamed: I2C3.3, R17.2
unnamed: I2C3.1, R20.2
unnamed: D5.A, R21.1
unnamed: PWR4.1, R21.2
unnamed: I2C4.3, R22.2
unnamed: I2C4.1, R25.2
unnamed: D6.A, R26.1
unnamed: PWR5.1, R26.2
unnamed: I2C5.3, R27.2
unnamed: I2C5.1, R30.2
unnamed: D7.A, R31.1
unnamed: PWR6.1, R31.2
unnamed: I2C6.3, R32.2
unnamed: I2C6.1, R35.2
unnamed: D8.A, R36.1
unnamed: PWR7.1, R36.2
unnamed: I2C7.3, R37.2
unnamed: I2C7.1, R40.2
unnamed: D9.A, R41.1
unnamed: PWR8.1, R41.2
unnamed: I2C8.3, R42.2
unnamed: I2C8.1, R45.2
unnamed: D10.A, R46.1
unnamed: PWR9.1, R46.2
unnamed: I2C9.3, R47.2
unnamed: I2C9.1, R50.2
unnamed: D11.A, R51.1
unnamed: PWR10.1, R51.2
unnamed: I2C10.3, R52.2
unnamed: I2C10.1, R55.2
unnamed: D12.A, R56.1
unnamed: PWR11.1, R56.2
unnamed: I2C11.3, R57.2
unnamed: I2C11.1, R60.2
unnamed: D13.A, R61.1
unnamed: PWR12.1, R61.2
unnamed: I2C12.3, R62.2
unnamed: I2C12.1, R65.2
unnamed: D14.A, R66.1
unnamed: PWR13.1, R66.2
unnamed: I2C13.3, R67.2
unnamed: I2C13.1, R70.2
unnamed: D15.A, R71.1
unnamed: PWR14.1, R71.2
unnamed: I2C14.3, R72.2
unnamed: I2C14.1, R75.2
unnamed: D16.A, R76.1
unnamed: PWR15.1, R76.2
unnamed: I2C15.3, R77.2
unnamed: I2C15.1, R80.2
unnamed: D17.A, R81.1
unnamed: PWR16.1, R81.2
unnamed: I2C16.3, R82.2
unnamed: I2C16.1, R85.2
unnamed: D18.A, R86.1
unnamed: PWR17.1, R86.2
unnamed: I2C17.3, R87.2
unnamed: I2C17.1, R90.2
unnamed: D19.A, R91.1
unnamed: PWR18.1, R91.2
unnamed: I2C18.3, R92.2
unnamed: I2C18.1, R95.2
unnamed: D20.A, R96.1
unnamed: PWR19.1, R96.2
unnamed: I2C19.3, R97.2
unnamed: I2C19.1, R100.2
unnamed: D21.A, R101.1
unnamed: PWR20.1, R101.2
unnamed: I2C20.3, R102.2
unnamed: I2C20.1, R105.2
unnamed: D22.A, R106.1
unnamed: PWR21.1, R106.2
unnamed: I2C21.3, R107.2
unnamed: I2C21.1, R110.2
unnamed: D23.A, R111.1
unnamed: PWR22.1, R111.2
unnamed: I2C22.3, R112.2
unnamed: I2C22.1, R115.2
unnamed: D24.A, R116.1
unnamed: PWR23.1, R116.2
unnamed: I2C23.3, R117.2
unnamed: I2C23.1, R120.2
unnamed: D25.A, R121.1
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

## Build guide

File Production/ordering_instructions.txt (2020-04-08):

panel size, 143x188mm
PCB thickness, 1.6mm
number of layers, 2
soldermask color, Red
silkscreen color, White
oz copper, 1oz
finish, HASL lead free
stencils, top
pcs per panel, 35
min trace width, 0.1778mm / 0.0070in
min drill size, 0.3810mm / 0.0150in

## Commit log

2020-04-06 pre-review changes
    [SGP30 Breakout.brd, SGP30 Breakout.sch]
2020-04-07 Post review/checklist changes
    [SGP30 Breakout.brd, SGP30 Breakout.sch]
2020-04-08 post qc-double check
    [SGP30 Breakout.brd]
2020-04-08 adding panel
    [SGP30 Breakout-Panel.GBL, SGP30 Breakout-Panel.GBO, SGP30 Breakout-Panel.GBP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]
2020-04-08 moving production folder out to root
    [SGP30 Breakout-Panel.GBL, SGP30 Breakout-Panel.GBO, SGP30 Breakout-Panel.GBP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]
2020-10-30 replacing 3.3V VREG with 1.8V in Schematic
    [SGP30 Breakout.sch]

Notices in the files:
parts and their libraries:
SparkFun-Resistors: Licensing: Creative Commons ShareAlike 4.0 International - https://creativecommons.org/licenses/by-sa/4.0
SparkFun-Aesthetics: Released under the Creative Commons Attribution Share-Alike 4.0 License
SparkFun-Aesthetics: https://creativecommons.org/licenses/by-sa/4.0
